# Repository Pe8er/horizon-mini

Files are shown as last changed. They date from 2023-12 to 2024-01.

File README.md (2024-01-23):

# Horizon *Mini* Keyboard






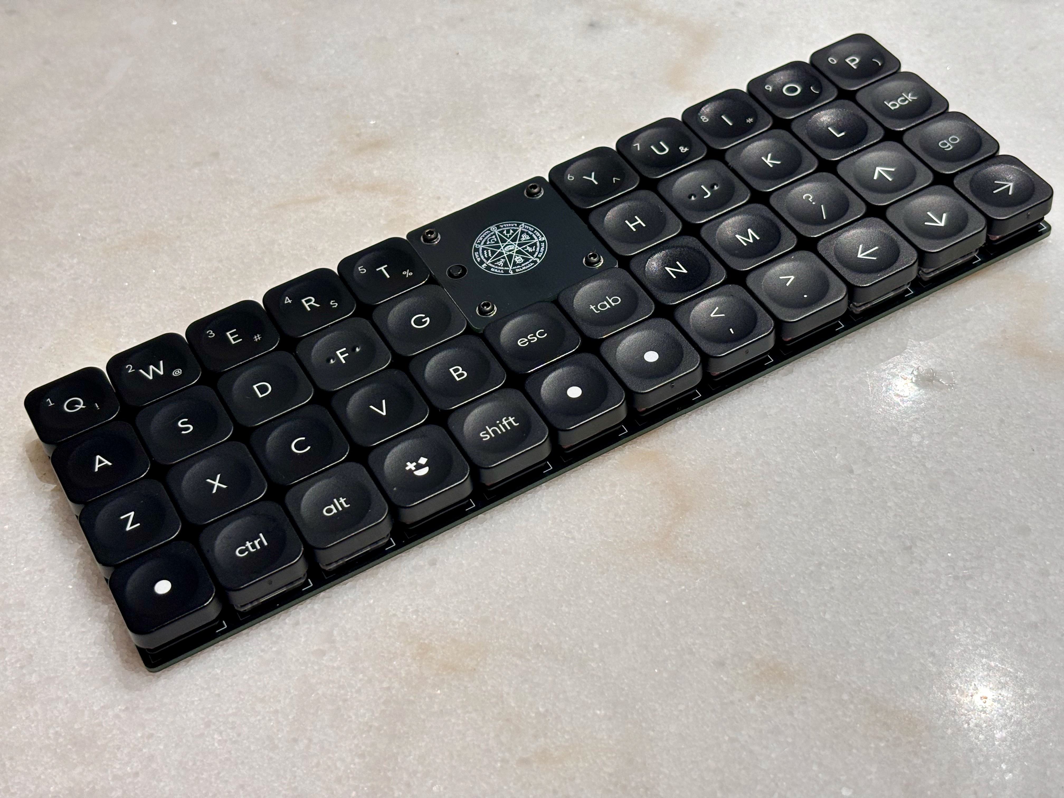
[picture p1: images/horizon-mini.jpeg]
Horizon Mini top photo


### Note:

This is a mod of the original, gorgeous Horizon. Changelog:

- Removed 2 columns
- Fully wireless: added battery connector & power switch
- Replaced Horizon logos with Tool (band) heptagram graphics

# [⬇️ Download latest Gerbers](https://github.com/Pe8er/horizon-mini/releases/latest)

### Original readme below 👇

# Horizon Keyboard

Horizon Choc + MX complete build top photo

Horizon is a 44 key (4x12) ortholinear keyboard, powered by an Arduino Pro Micro.

This keyboard is a grid of 1U keys with no special features: no hotswap, no RGB, no OLED screen, no knobs.

## Project structure

* [`gerbers`](gerbers): Gerber files for PCB manufacturing
* [`graphics`](graphics): Source assets for PCB silkscreen
* [`kicad`](kicad): KiCad project files (schematics and PCB designs)
* [`kicad-libraries`](kicad-libraries): KiCad components and footprints
* [`kicad-plugins`](kicad-plugins): KiCad Pcbnew Python plugins
* [`images`](images): Images for project documentation

## PCBs

Two separate PCB designs are available for MX and Choc keyswitches, with their respective footprints and key spacing (MX: 19mm x 19mm, Choc: 18mm x 17mm).

Each design consists of a main PCB, a top plate to protect the microcontroller, and a bottom plate to protect the bottom components:

Horizon MX PCBs photo

The bottom plate is a cutout of all the components exposed through the bottom of the main PCB, and screws *directly* against the main PCB. This nicely guards you and your desk surface from all the pointy through-hole bits, while retaining a low keyboard height:

Horizon Choc + MX complete build bottom photo

## KiCad project notes

The bottom and top plates are generated via a custom KiCad 7 Python SWIG plugin [Horizon Board Producer](kicad-plugins/horizon-board-producer-plugin.py).

For the plugin to generate these plate boards, the PCB and its footprints use the following layer convention:

* `F.Adhesive` designates top plate holes and edge cuts.
* `B.Adhesive` designates bottom plate holes and edge cuts.

When the board producer runs, these layers are used as follows:

* On the board and footprints:
    * Graphics on the plate's designated layer will be moved to `Edge.Cuts` when producing that plate.
    * As with all edge cuts, please make sure your graphics are non-overlapping closed shapes.
* On footprints only:
    * Pads of type "SMD Aperture" and shape "Circular/Oval" on the plate's designated layer will be converted to proper NPTH pads.
    * Note only circular/oval shapes are supported for these pads, because they are the only available hole/drill shapes. If you need a fancy plate cutout shape on your footprint, then draw graphics lines on the designated layer.
    * **IMPORTANT**: When adding pads solely for plate cutout purposes, set the technical layer to just the designated plate cutout layers. Leave all other technical layers unchecked.

Horizon KiCad plate edge cuts
Horizon KiCad footprint plate holes

Additionally, the board producer plugin will preserve any in-bounds "H" footprint pads (mounting holes), "LOGO" footprint graphics (custom silkscreen art), and board silkscreen on the plates. Other items which are not needed for plates (e.g., copper tracks and zones) are removed from the plates.

The board producer plugin also generates all the Gerber files for production.

Please note the board producer plugin expects the following folder structure:

* The KiCad PCB file is two folders deep from the project root, e.g., `kicad/[board-version]/[board-name].kicad_pcb`
* When the plugin executes, a folder called `temp` is created in the project root to store any temporary files created.
    * Each time the board producer runs, any existing files in this temporary folder are deleted.

**IMPORTANT:** If you would like to use this plugin and plate edge cuts convention for you own project, please make sure you carefully examine the output Gerber files! The plugin ultimately worked well for my case, but you might need to make adjustments to the plugin to suit your project. And to reduce the chance of being charged extra money by PCB manufacturers, use footprint plate holes instead of edge cuts whenever reasonable to do so.

**IMPORTANT:** This plugin uses `pcbnew.LoadBoard()` to load copies of the PCB, which is [not safely supported in a running instance of KiCad](https://forum.kicad.info/t/the-loadboard-function-is-invalid/31238/9). To avoid project integrity problems this may cause to the running KiCad instance, the plugin forcefully exits KiCad upon execution completion.

## Keyboard firmware

* ZMK only. Horizon Mini's shield definition is in [Pe8er's zmk-config](https://github.com/Pe8er/zmk-config-horizon-mini).

## Bill of materials

For PCBs, keyswitches, and keycaps, get parts depending on your desired keyswitch type.

Part | Purpose | Quantity | Notes | Vendor URL
---- | ------- | -------- | --------- | ----------
Main PCB  | circuit board | 1 | | Send Gerber zip files to [JLCPCB](https://jlcpcb.com/).
Top plate PCB  | protects microcontroller | 1 | 
Bottom plate PCB  | protects bottom pins and components | 1 |
Arduino Pro Micro | Microcontroller board | 1 | Or use another Pro Micro compatible board with same dimensions (confirmed Elite-C V4, nice!nano 2.0, and Adafruit KB2040 fit) | [AliExpress (TENSTAR ROBOT) - Micro USB 3-18V](https://www.aliexpress.com/item/32849563958.html)
Sockets | so you don't need to solder the MCU itself | 1 | | [Aliexpress](https://www.aliexpress.com/item/1777652709.html?spm=a2g0o.order_list.order_list_main.29.55371802cNThgI)
MSK-12C02 | Power switch | 1 | | [Aliexpress](https://www.aliexpress.com/item/4000685483225.html?spm=a2g0o.order_list.order_list_main.11.55371802cNThgI)
6x6mm DIP 4-pin tactile switch | Reset button | 1 | | [AliExpress (xin cheng electronic)- 6x6x10mm](https://www.aliexpress.com/item/32912263133.html)
1N4148 SOD-123 | Diodes for keyboard row-column matrix | 52 | | [AliExpress (DSSRQI) - 1N4148 SOD-123](https://www.aliexpress.com/item/4000331408283.html)
Battery | to eliminate wires | 1
Battery socket | to plug into the PCB | 1
Keyswitches |  | 44 | PCB mount (5 pin) switches recommended | MX: [AliExpress (KPrepublic) - Gateron Switch RGB 5pin Clear](https://www.aliexpress.com/item/3256801798608641.html), Choc: [MKUltra Corporation - Kailh Low Profile Choc Switches](https://mkultra.click/choc-switches)
Keycaps |  | 44 | | MX: [AliExpress (Cool Jazz)- DSA 1U Keycaps](https://www.aliexpress.com/item/2251832643863132.html), Choc: [MKUltra Corporation - MBK Choc Keycaps](https://mkultra.click/mbk-choc-keycaps) / [wrk. Legend](https://worklouder.cc/shop/wrk-legend/)
M2 6mm screws | Secure main PCB and plate PCBs | 8 | | [AliExpress (wuhushiyu) - 200PCS-M2 Mix - Black](https://www.aliexpress.com/item/32862529967.html)
M2 nuts | Secure main PCB and plate PCBs | 8 | | See M2 set above
M2 8mm male-female standoffs | Raise top plate PCB above microcontroller | 4 | | See M2 set above
2mm tall rubber bumpons | Raise board above desk surface and provide skid resitance | 6 | Shop around - you can get cheaper alternatives if you don't need 96 of them! | [Amazon - 3M SJ5302 Clear Bumpon Blister Pack (96 Bumpons)](https://www.amazon.com/SJ5302-Clear-Bumpon-Blister-Bumpons/dp/B01ACPT2LU) / [Aliexpress](https://www.aliexpress.com/item/32962113640.html?spm=a2g0o.order_list.order_list_main.5.55371802cNThgI) / [Aliexpress](https://www.aliexpress.com/item/1005005615951861.html?spm=a2g0o.order_list.order_list_main.17.55371802cNThgI)

M2 standoff height requirements are dependent on the seated microcontroller height. An M2 spacer set should give you enough options. I recommend getting a reset button ~2mm taller than the M2 standoffs so the button is level with the top plate.

If using a LiPo battery and a bluetooth Pro Micro compatible board, then use battery size 301230. Just make sure the microcontroller socket height provides clearance for the battery to fit underneath (standard SIP sockets are a common choice).

## PCB manufacturing settings

These are the manufacturing settings I used when ordering from JLCPCB:

* **Base Material**: FR4
* **Layers**: 2
* **Dimensions**: (whatever the gerber file specifies)
* **PCB Qty**: 5
* **Different Design**: 1
* **Delivery Format**: Single PCB
* **PCB Thickness**: 1.6
* **PCB Color**: Black
* **Silkscreen**: White
* **Surface Finish**: LeadFree HASL-RoHS
* **Outer Copper Weight**: 1 oz
* **Gold Fingers**: No
* **Confirm Production File**: No
* **Flying Probe Test**: Fully Test
* **Castellated Holes**: No
* **Remove Order Number**: Specify a location

**IMPORTANT:** All PCBs have ["JLCJLCJLCJLC" silkscreen text](https://support.jlcpcb.com/article/28-how-to-remove-order-number-from-your-pcb) underneath the Pro Micro footprint. If you want to remove the order number from the boards or you want to print the PCBs with another manufacturer, then I recommend removing this silkscreen text from the `.kicad_pcb` file, and then re-run the Horizon Board Producer plugin to create the updated Gerber files.

## Build tips

* The main PCB uses a ground plane, so ground pads are more stubborn to solder. Make sure your soldering tip has good surface area coverage across the pad and component leg. If your soldering iron supports it, turning up the temperature a bit can help too.
* Before soldering the keyswitches, make sure they are perfectly straight and fully inserted into the PCB. Put the keycaps on the inserted keyswitches, and give a thorough visual inspection for any spacing or height irregularities between the keycaps. For MX builds, Gateron switches in particular have thicker PCB-mount pins - push these keyswitches in hard to make sure they are fully inserted!
* To get a perfect fit between the main PCB and bottom plate, keep your soldering tidy! Clean any excess solder/flux which falls outside the bounds of the bottom plate cutouts.
* Attaching the main PCB and the bottom plate requires a very steady hand. The approach that worked best for me was using narrow tweezers to grip the edges of the hex nut against the main PCB, while driving in the screw from the bottom plate.
* The top plate is a very tight fit. If the inner keycaps rub against it, first ensure the top plate is perfectly centered. To center it, slide a thin piece of cardstock in-and-out between the inner keycaps and the top plate on all sides. If that does not resolve the keycaps rubbing, then remove the top plate, sand its edges a bit, and try again.

## Revision history

* **Rev1** (2021-07-30 - not publicly released):
    * PCB: Experimental prototype of MX board.
    * Schematic: Wire as 42 key 7x6 matrix (original release only had 6 keys on bottom row).
* **Rev2** (2021-09-26)
    * PCB: Create MX and Choc boards with bottom and top plates.
    * Schematic: Wire as 52 key 4x14 matrix.
* **Rev2.1** (2021-10-24)
    * PCB: Slightly improve thermal relief clearance to make soldering ground pads easier.
* **Rev2.2** (2021-10-25)
    * Horizon Board Producer plugin: Now supports converting designated placeholder pads to NPTH pads during plate generation.
    * Footprints: Replace graphics which indicate plate cutouts with placeholder pads which indicate plate NPTH pads.
    * PCB: Gerber files regenerated using updated board producer plugin.
* **Rev2.3** (2022-03-21)
    * Horizon Board Producer plugin: Upgrade to KiCad 6
    * PCB, Schematic: No physical changes. Files upgraded to KiCad 6, and Gerber files regenerated using updated files.
* **Rev2.4** (2023-11-09)
    * Horizon Board Producer plugin: Upgrade to KiCad 7
    * PCB, Schematic: No physical changes. Files upgraded to KiCad 7, and Gerber files regenerated using updated files.

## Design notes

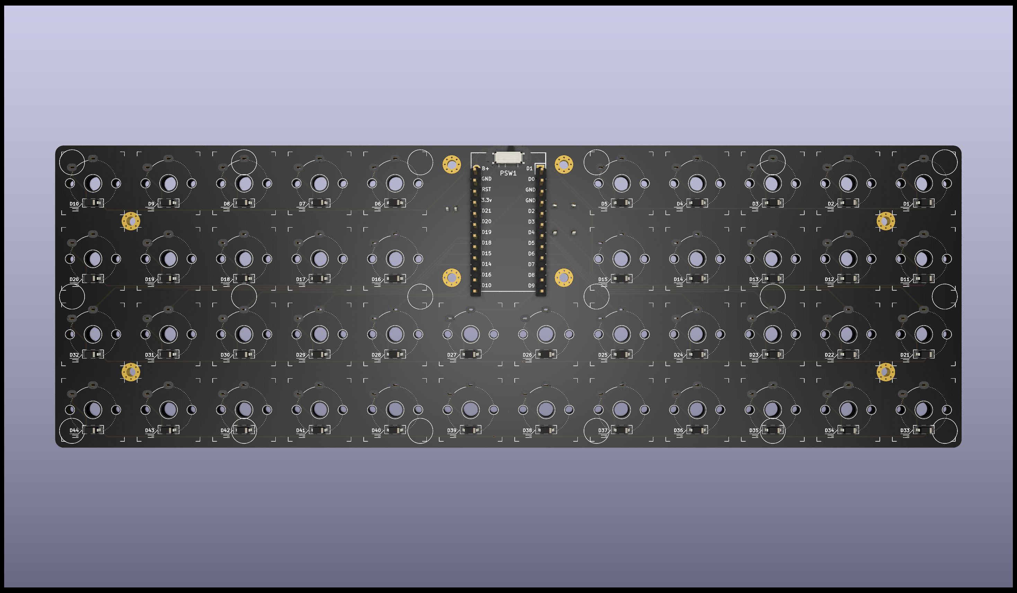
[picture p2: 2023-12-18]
kicad/choc mx spacing/horizon-choc-mini-mx-spacing-bottom.jpg

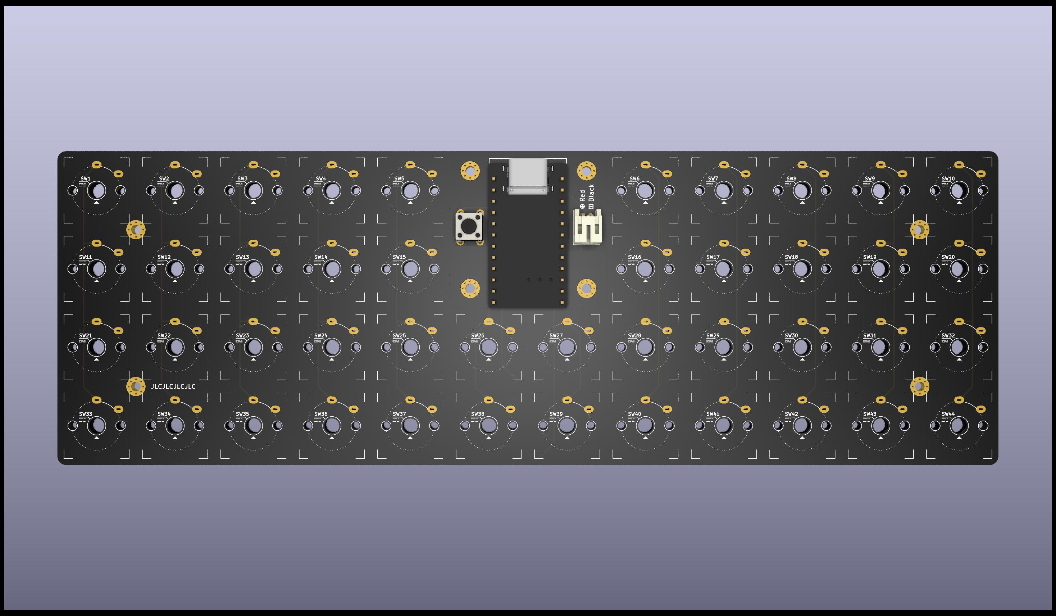
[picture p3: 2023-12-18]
kicad/choc mx spacing/horizon-choc-mini-mx-spacing-top.jpg

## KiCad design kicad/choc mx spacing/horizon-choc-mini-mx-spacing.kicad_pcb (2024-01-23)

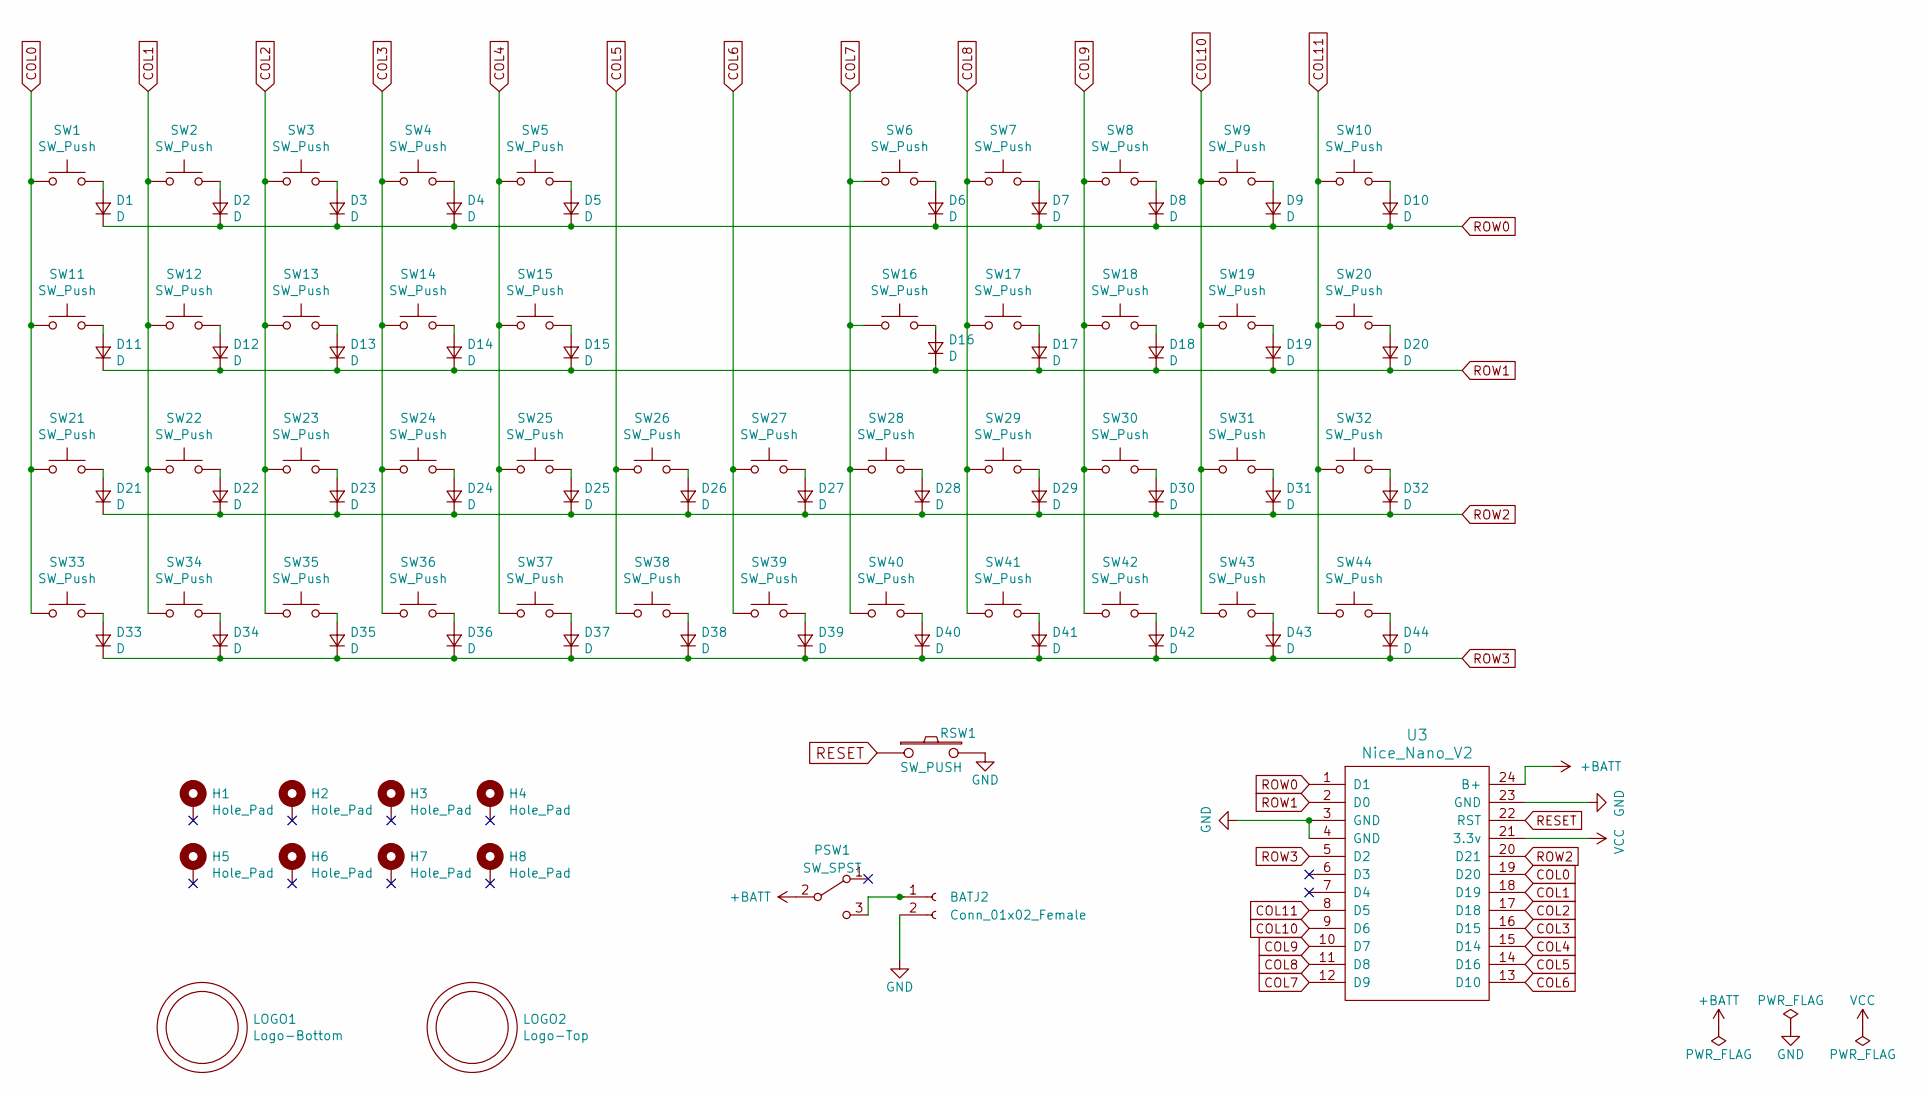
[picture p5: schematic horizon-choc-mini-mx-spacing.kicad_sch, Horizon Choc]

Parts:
BATJ2: Conn_01x02_Female; JST_PH_S2B-PH-K_1x02_P2.00mm_Horizontal
D1, D2, D3, D4, D5, D6, D7, D8, D9, D10, D11, D12, D13, D14, D15, D16, D17, D18, D19, D20, D21, D22, D23, D24, D25, D26, D27, D28, D29, D30, D31, D32, D33, D34, D35, D36, D37, D38, D39, D40, D41, D42, D43, D44: D; D_SOD-123
H1, H2, H3, H4, H5, H6, H7, H8: Hole_Pad; Mount_M2
LOGO1: Logo-Bottom; bloodborne_moon
LOGO2: Logo-Top; bloodborne_moon
PSW1: SW_SPST; SW_SPDT_PCM12
RSW1: SW_PUSH; SW_Push_6mm
SW1, SW2, SW3, SW4, SW5, SW6, SW7, SW8, SW9, SW10, SW11, SW12, SW13, SW14, SW15, SW16, SW17, SW18, SW19, SW20, SW21, SW22, SW23, SW24, SW25, SW26, SW27, SW28, SW29, SW30, SW31, SW32, SW33, SW34, SW35, SW36, SW37, SW38, SW39, SW40, SW41, SW42, SW43, SW44: SW_Push; SW_Choc_MX
U3: Nice_Nano_V2; Nice_Nano_V2_Flipped

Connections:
+BATT: PSW1.2 (B), U3.24 (B+)
COL0: SW1.1, SW11.1, SW21.1, SW33.1, U3.19 (D20)
COL1: SW2.1, SW12.1, SW22.1, SW34.1, U3.18 (D19)
COL2: SW3.1, SW13.1, SW23.1, SW35.1, U3.17 (D18)
COL3: SW4.1, SW14.1, SW24.1, SW36.1, U3.16 (D15)
COL4: SW5.1, SW15.1, SW25.1, SW37.1, U3.15 (D14)
COL5: SW26.1, SW38.1, U3.14 (D16)
COL6: SW27.1, SW39.1, U3.13 (D10)
COL7: SW6.1, SW16.1, SW28.1, SW40.1, U3.12 (D9)
COL8: SW7.1, SW17.1, SW29.1, SW41.1, U3.11 (D8)
COL9: SW8.1, SW18.1, SW30.1, SW42.1, U3.10 (D7)
COL10: SW9.1, SW19.1, SW31.1, SW43.1, U3.9 (D6)
COL11: SW10.1, SW20.1, SW32.1, SW44.1, U3.8 (D5)
GND: BATJ2.2, U3.3 (GND), U3.4 (GND), U3.23 (GND); also elsewhere on the board
unnamed: BATJ2.1, PSW1.3 (C)
unnamed: D1.2 (A), SW1.2
unnamed: D2.2 (A), SW2.2
unnamed: D3.2 (A), SW3.2
unnamed: D4.2 (A), SW4.2
unnamed: D5.2 (A), SW5.2
unnamed: D6.2 (A), SW6.2
unnamed: D7.2 (A), SW7.2
unnamed: D8.2 (A), SW8.2
unnamed: D9.2 (A), SW9.2
unnamed: D10.2 (A), SW10.2
unnamed: D11.2 (A), SW11.2
unnamed: D12.2 (A), SW12.2
unnamed: D13.2 (A), SW13.2
unnamed: D14.2 (A), SW14.2
unnamed: D15.2 (A), SW15.2
unnamed: D16.2 (A), SW16.2
unnamed: D17.2 (A), SW17.2
unnamed: D18.2 (A), SW18.2
unnamed: D19.2 (A), SW19.2
unnamed: D20.2 (A), SW20.2
unnamed: D21.2 (A), SW21.2
unnamed: D22.2 (A), SW22.2
unnamed: D23.2 (A), SW23.2
unnamed: D24.2 (A), SW24.2
unnamed: D25.2 (A), SW25.2
unnamed: D26.2 (A), SW26.2
unnamed: D27.2 (A), SW27.2
unnamed: D28.2 (A), SW28.2
unnamed: D29.2 (A), SW29.2
unnamed: D30.2 (A), SW30.2
unnamed: D31.2 (A), SW31.2
unnamed: D32.2 (A), SW32.2
unnamed: D33.2 (A), SW33.2
unnamed: D34.2 (A), SW34.2
unnamed: D35.2 (A), SW35.2
unnamed: D36.2 (A), SW36.2
unnamed: D37.2 (A), SW37.2
unnamed: D38.2 (A), SW38.2
unnamed: D39.2 (A), SW39.2
unnamed: D40.2 (A), SW40.2
unnamed: D41.2 (A), SW41.2
unnamed: D42.2 (A), SW42.2
unnamed: D43.2 (A), SW43.2
unnamed: D44.2 (A), SW44.2
RESET: U3.22 (RST); also elsewhere on the board
ROW0: D1.1 (K), D2.1 (K), D3.1 (K), D4.1 (K), D5.1 (K), D6.1 (K), D7.1 (K), D8.1 (K), D9.1 (K), D10.1 (K), U3.1 (D1)
ROW1: D11.1 (K), D12.1 (K), D13.1 (K), D14.1 (K), D15.1 (K), D16.1 (K), D17.1 (K), D18.1 (K), D19.1 (K), D20.1 (K), U3.2 (D0)
ROW2: D21.1 (K), D22.1 (K), D23.1 (K), D24.1 (K), D25.1 (K), D26.1 (K), D27.1 (K), D28.1 (K), D29.1 (K), D30.1 (K), D31.1 (K), D32.1 (K), U3.20 (D21)
ROW3: D33.1 (K), D34.1 (K), D35.1 (K), D36.1 (K), D37.1 (K), D38.1 (K), D39.1 (K), D40.1 (K), D41.1 (K), D42.1 (K), D43.1 (K), D44.1 (K), U3.5 (D2)
VCC: U3.21 (3.3v)

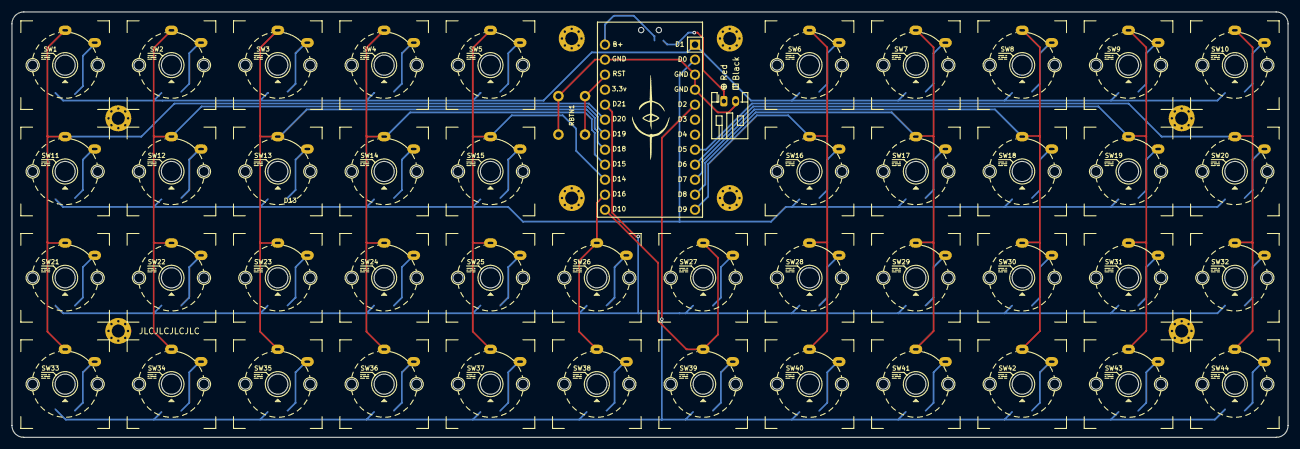
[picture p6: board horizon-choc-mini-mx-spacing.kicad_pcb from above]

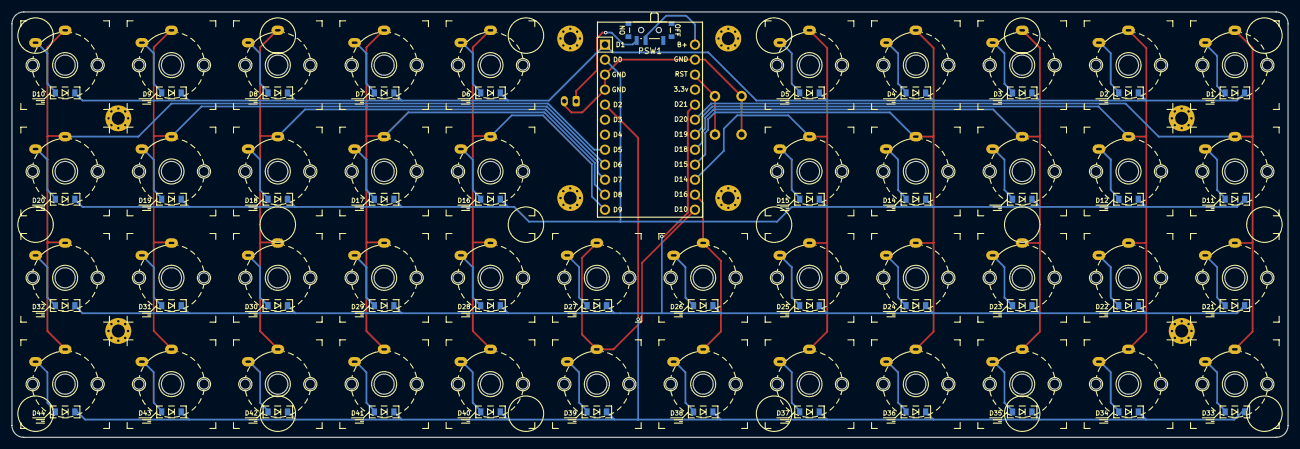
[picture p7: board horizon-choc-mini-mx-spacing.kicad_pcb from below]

Board: 2 copper layers, 216.0 x 72.0 mm, 102 parts (45 on the bottom side), 64 nets.

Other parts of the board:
RBTN1: SW_PUSH; SW_Push_6mm

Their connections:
GND: RBTN1.2; also elsewhere on the board
RESET: RBTN1.1; also elsewhere on the board

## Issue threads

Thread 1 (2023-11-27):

1.0.0 Testing

Pe8er, 2023-11-27:
- [x] All switches
- [x] Reset button
- [x] Controller
- [x] [Create and test firmware](https://github.com/Pe8er/zmk-config-horizon-mini)
- [x] Power switch - DOESN'T WORK
- [x] Battery charging - DOESN'T WORK
- [x] Wireless operation - DOESN'T WORK

Closed 2023-12-04.

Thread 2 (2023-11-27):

1.1.0 Tweaks and new features

Pe8er, 2023-11-27:
# Blockers
- [x] [Finalize firmware](https://github.com/Pe8er/zmk-config-horizon-mini)
- [x] Confirm that keycaps fit (wait for the prototype to arrive)
- [x] Fix power switch and battery connector
- [x] Rewire the whole bloody thing
- [x] Bottom plate holes for battery connector
- [x] Increase vertical switch spacing by 0.5mm so that wrk caps don't rub against each other

# Important
- [x] Go back to the schematic and clean it up
- [x] Update MCU footprint to nice!nano

# Bullshit
- [x] Add teardrops
- [x] Make footprints more descriptive: battery connector
- [x] Graphics on the bottom plate?
- [x] Different logo?
- [x] Add rubber feet markings
- [x] Make footprints more descriptive: diodes
- [ ] ~~Figure out a push type of power switch and position it opposite of reset button~~

Closed 2023-12-18.

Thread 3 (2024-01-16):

Controller footprint is reversed

Pe8er, 2024-01-16:
I had to re-solder the pins and flip it upside down…

Closed 2024-01-23.

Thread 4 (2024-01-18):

Battery doesn't charge?

Pe8er, 2024-01-18:

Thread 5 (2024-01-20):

Power switch label is flipped

Pe8er, 2024-01-20:

Closed 2024-01-23.

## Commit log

2023-08-31 First upload
    [horizon-choc-mini.kicad_pcb, horizon-choc-mini.kicad_sch, horizon-choc.kicad_pcb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]
2023-11-09 Almost there
    [horizon-choc-mini.kicad_pcb]
2023-11-14 Submitting to JLCPCB!
    [horizon-choc-mini.kicad_pcb]
2023-12-18 - Updated and cleaned wiring - Added bottom plate holes for battery connector - New graphics (Tool heptagram) - Added teardrops - Added rubber feet markings - Made footprints more descriptive: diodes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
    [horizon-choc-mini-mx-spacing.kicad_pcb, horizon-choc-mini-mx-spacing.kicad_sch, horizon-choc-mini.kicad_pcb]
2023-12-18 Add board renders
2024-01-23 - Fix flipped MCU footprint - Fix power switch label
    [horizon-choc-mini-mx-spacing.kicad_pcb, horizon-choc-mini-mx-spacing.kicad_sch]
